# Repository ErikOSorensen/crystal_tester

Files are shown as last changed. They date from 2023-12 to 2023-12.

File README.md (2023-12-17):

# Crystal tester
Creating pcbs for crystal tester (for measuring motional parameters for crystal filters).

- 2023-12-17: First G3UUR board populated.
- 2023-12-17: First crystals tested.

## The tester

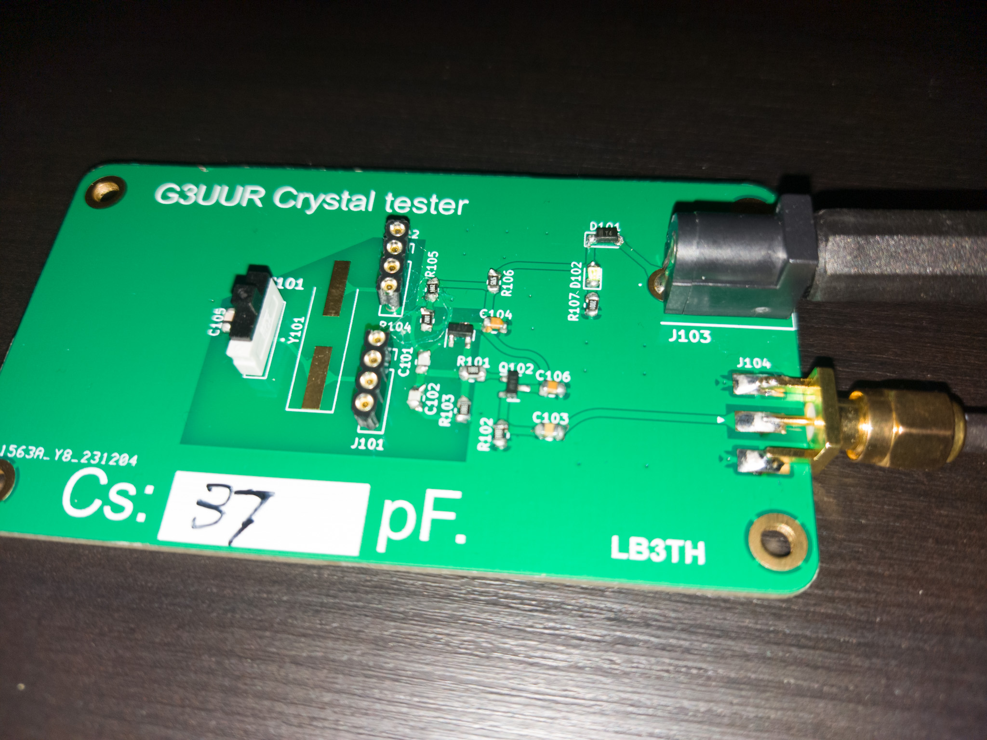
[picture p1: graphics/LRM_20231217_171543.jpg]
The populated PCB


## First tests

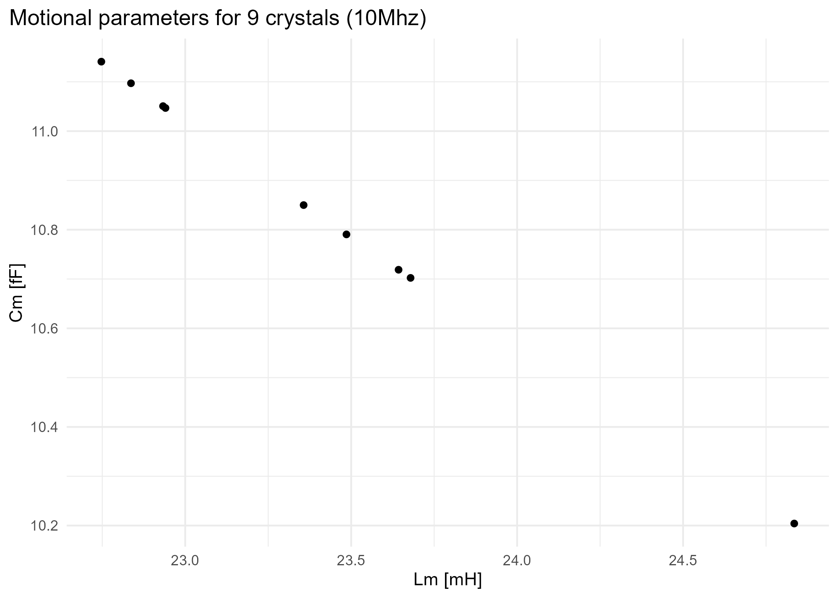
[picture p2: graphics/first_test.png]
Data from the first 9 crystals


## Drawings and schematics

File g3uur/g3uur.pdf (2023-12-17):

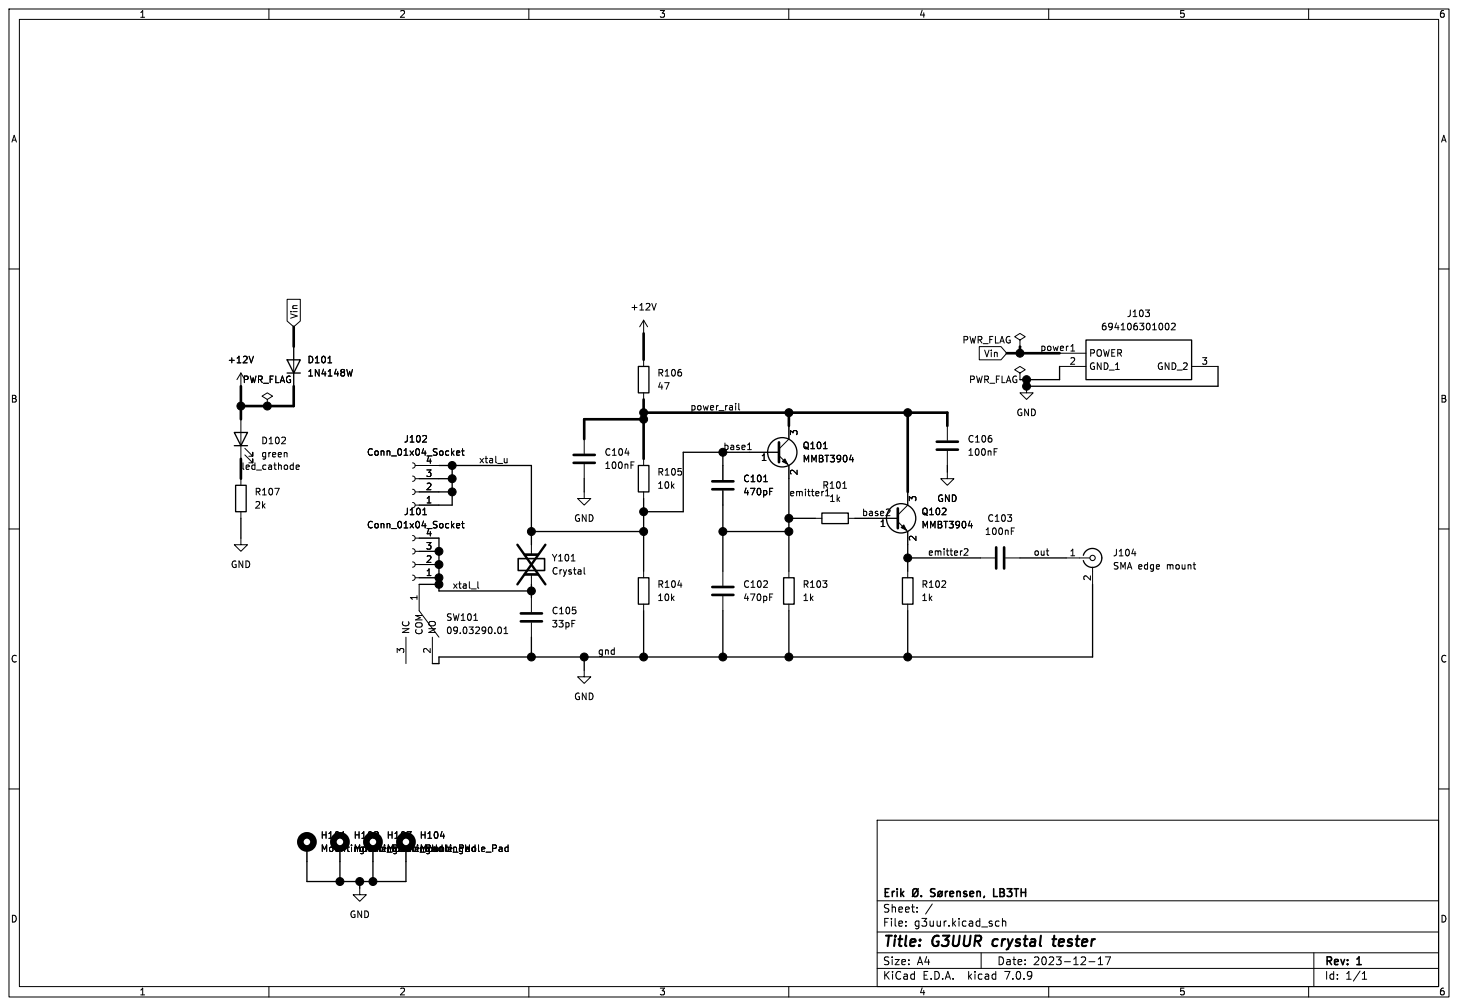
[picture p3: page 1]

J104 SMA edge mount GND

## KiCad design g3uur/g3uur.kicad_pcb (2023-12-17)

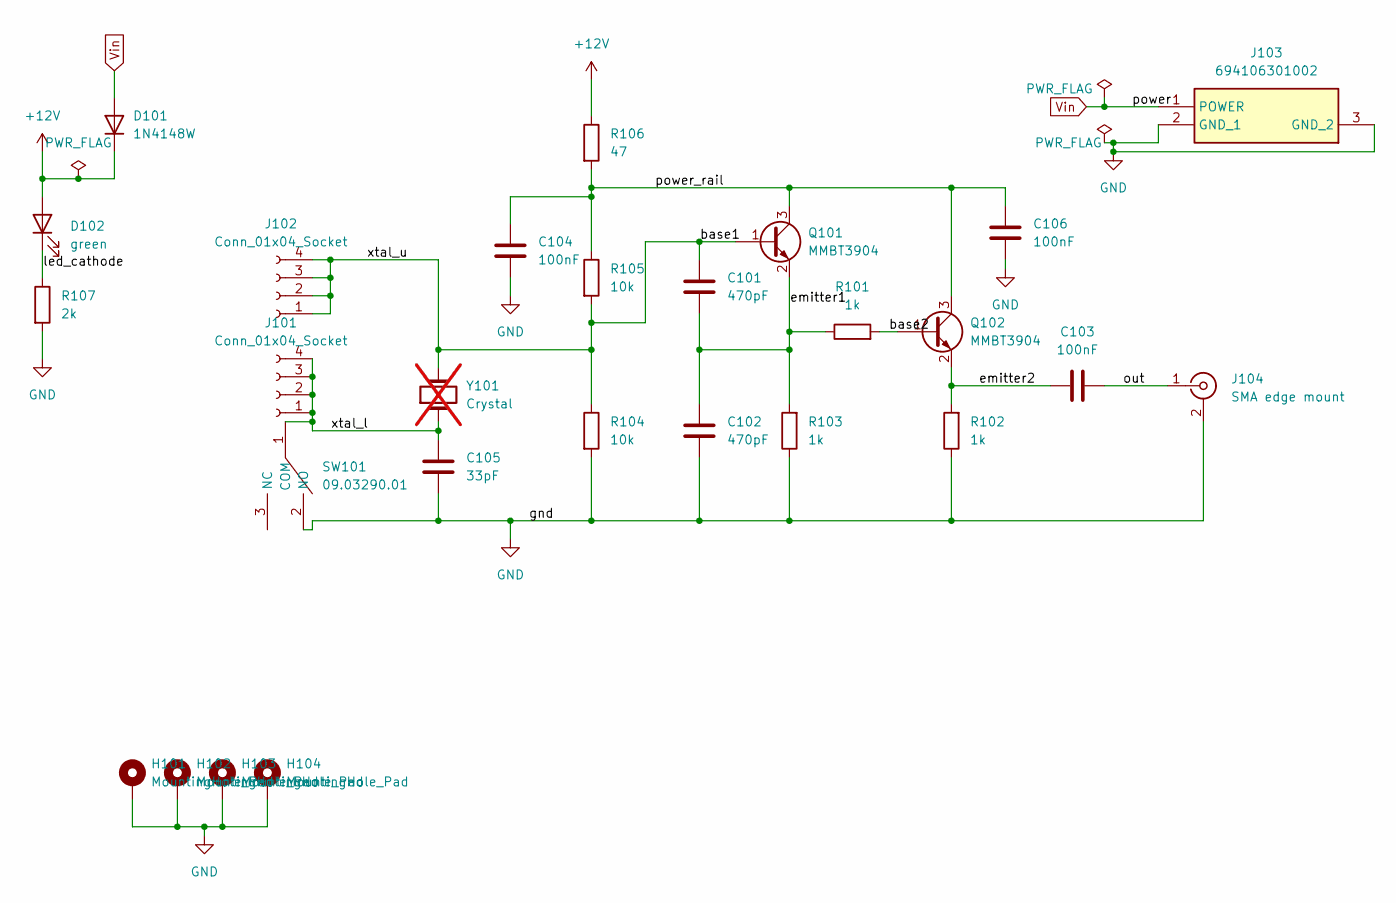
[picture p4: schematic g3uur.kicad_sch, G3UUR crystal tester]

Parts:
C101, C102: 470pF; C_0805_2012Metric
C103, C104, C106: 100nF; C_0805_2012Metric
C105: 33pF; C_0805_2012Metric
D101: 1N4148W; D_SOD-123
D102: green; LED_0805_2012Metric_Pad1.15x1.40mm_HandSolder
H101, H102, H103, H104: MountingHole_Pad; MountingHole_3.2mm_M3_DIN965_Pad_TopBottom
J101, J102: Conn_01x04_Socket; PinSocket_1x04_P2.54mm_Vertical
J103: 694106301002; 694106301002_1; Mouser Part Number 710-694106301002
J104: SMA edge mount; SMA_Molex_73251-1153_EdgeMount_Horizontal
Q101, Q102: MMBT3904; SOT-23
R101, R102, R103: 1k; R_0805_2012Metric
R104, R105: 10k; R_0805_2012Metric
R106: 47; R_0805_2012Metric
R107: 2k; R_0805_2012Metric
SW101: 09.03290.01; 090329001; Mouser Part Number 123-09.03290.01
Y101: Crystal; Crystal_SMD_HC49-SD_HandSoldering; not fitted

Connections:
+12V: D101.1 (K), D102.2 (A), R106.1
/base1: C101.1, J102.1, J102.2, J102.3, J102.4, Q101.1 (B), R104.1, R105.2, Y101.2
/base2: Q102.1 (B), R101.2
/emitter1: C101.2, C102.1, Q101.2 (E), R101.1, R103.2
/emitter2: C103.1, Q102.2 (E), R102.2
/led_cathode: D102.1 (K), R107.1
/out: C103.2, J104.1 (In)
/power_rail: C104.1, C106.1, Q101.3 (C), Q102.3 (C), R105.1, R106.2
/xtal_l: C105.1, J101.1, J101.2, J101.3, J101.4, SW101.1 (COM), Y101.1
GND: C102.2, C104.2, C105.2, C106.2, H101.1, H102.1, H103.1, H104.1, J103.2 (GND_1), J103.3 (GND_2), J104.2 (Ext), R102.1, R103.1, R104.2, R107.2, SW101.2 (NO)
Vin: D101.2 (A), J103.1 (POWER)

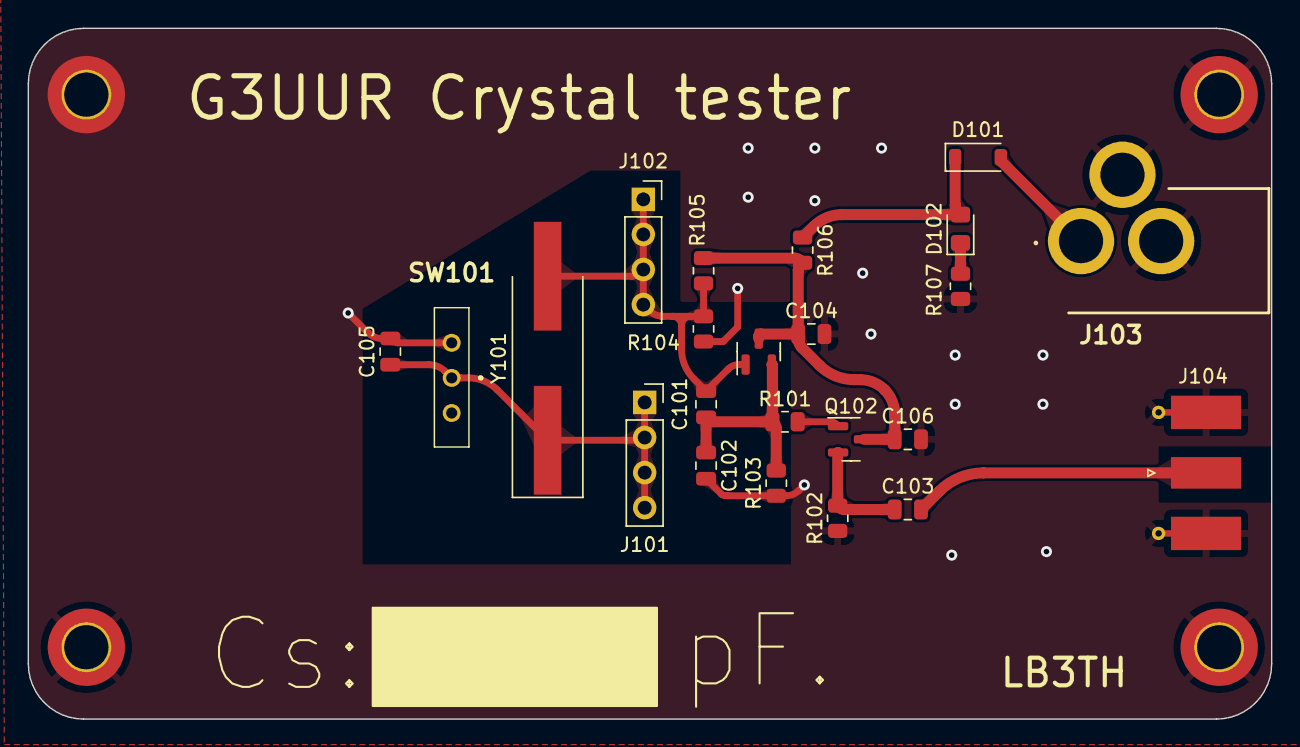
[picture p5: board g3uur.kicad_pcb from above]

Board: 2 copper layers, 90.0 x 50.0 mm, 27 parts (0 on the bottom side), 11 nets.

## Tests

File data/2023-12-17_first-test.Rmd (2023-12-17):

---
title: "Testing some crystals"
author: "Erik Ø. Sørensen"
date: "`r Sys.Date()`"
output: html_document
---

```{r setup, include=FALSE}
knitr::opts_chunk$set(echo = TRUE)
library(tidyverse)
```

```{r}
df <- read_csv("2023-12-17_crystals.csv")
```

The formulas for the crystal motional parameters are 
$$C_m = \frac{2(C_s+C_0)\Delta f}{f} $$ and
$$L_m = \frac{1}{(2\pi f)^2C_m}.$$
I have measured 9 crystals that are nominally 10 MHz.
I have also measured the additional capacitance added by the tester to 37 pF. 

The crystals themselves (sourced from ebay) seem to resonate a bit below 10MHz:

```{r}
df |> ggplot(aes(x=f0)) + 
  geom_histogram(bins=3) + 
  labs(x = "Resonance [MHz]") +
  theme_minimal() +
  theme(plot.title.position = "plot")
```

The formulas for the motional parameters can be coded as
```{r}
cm <- function(cs, c0, f0, f1)  {
  2 * (cs+c0)*(1e-12)*(f1-f0)*1e6 / (f0*1e6)
}
lm <- function(cs, c0, f0, f1) {
  cms <- cm(cs, c0, f0, f1)
  1 / ( (2*pi * f0 *1e6)^2 *cms)
}
```

Now, let's try to graph these parameters
```{r}
df_cm <- df |> mutate(Cm = cm(37,cp,f0,f1),
                   Lm = lm(37,cp,f0,f1))
df_cm |> ggplot(aes(x = Lm * 1e3, y = Cm*1e15)) +
  geom_point() + 
  theme_minimal() +
  theme(plot.title.position = "plot") +
  labs(x = "Lm [mH]", y = "Cm [fF]", title="Motional parameters for 9 crystals (10Mhz)")
ggsave("../graphics/first_test.png")
```

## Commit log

2023-12-17 First production attempt.
    [g3uur.kicad_pcb, g3uur.kicad_sch]
2023-12-17 Schematic pdf.
2023-12-17 First attempts at testing crystals.
    [2023-12-17_crystals.csv]
